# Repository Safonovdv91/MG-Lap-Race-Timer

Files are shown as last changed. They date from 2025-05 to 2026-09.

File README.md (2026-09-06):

# Проект MG-Lap-Race-Timer
Фотобарьер работающий на базе esp32-s3(или аналоги). Проектирование вед я создал проект, опиши мне подробную инструкцию по реализации схемы,
**MG-Lap-Race-Timer** — это система хронометража для спортивных мероприятий, использующая инфракрасные (ИК - TSAL6200, или аналог, Лазерный 940 нм) излучатель и фотодиод(BPW34, vishay ) для отслеживания времени круга и скорости. Система состоит из двух основных компонентов: **передатчика** и **приемника**, оба на базе микроконтроллера ESP32.

## Основные возможности

- **Измерение времени круга:** Точное отслеживание времени прохождения круга.
- **Измерение скорости:** Расчет скорости на основе времени пересечения луча.
- **Веб-интерфейс:** Удобный интерфейс для просмотра результатов в реальном времени, доступный с любого устройства с Wi-Fi.
- **Беспроводная телеметрия:** Передатчик отправляет данные о состоянии своей батареи на приемник.
- **Гибкая настройка:** Возможность изменения режимов работы и других параметров через веб-интерфейс.

## Архитектура

Система разделена на два устройства:

### 1. Передатчик (Transmitter)

- **Задача:** Генерировать постоянный ИК-сигнал или Laser-сигнал.
- **Функционал:**
  - ИК (LASER)-сигнал.
  - Измерение напряжения аккумулятора
  - Передача телеметрии(напряжение, вкл \выкл луч) по ESP-NOW на Receiver
  - Отображение заряда через LED
  - Hearbeat работы

 - **Принцип работы**
 - Шим сигнал ESP32 на GPIO13 D13 (частота 38кГц) через транзиcтор IRLZ44N.
  При duty = 50% использую х2 мощность(200мА) - TSAL6200

### 2. Приемник (Receiver)

- **Задача:** Обнаруживать пересечение ИК-луча и предоставлять интерфейс для пользователя.
- **Функционал:**
  - Создает точку доступа Wi-Fi.
  - Запускает веб-сервер, доступный по адресу `http://192.168.4.1`.
  - Регистрирует пересечение ИК(лазерного)-луча.
  - Рассчитывает время круга.
  - Отображает историю измерений.
  - Принимает и отображает данные телеметрии от передатчика.
  - Трансляция ESP-NOW с данными времени.

## Веб-интерфейс

Приемник предоставляет веб-интерфейс со следующими возможностями:

- **Выбор режима:**
  - **Секундомер круга (Lap Timer):** Измеряет время между двумя последовательными пересечениями одного датчика.
  - **Гоночный таймер (Race Timer):** Работает как стандартный секундомер, запускаемый первым датчиком и останавливаемый вторым.
- **Отображение данных:** Показывает текущее измерение, историю последних 5 измерений, а также состояние батарей приемника и передатчика.
- **Настройки:** Позволяет изменять расстояние между датчиками ( для режима спидометра) и настраивать параметры Wi-Fi.

## Аппаратное обеспечение

- **Микроконтроллер:** ESP32 DevKit V1 (или аналогичный).
- **Передатчик:** 
  - ИК-светодиоды(940нМ), laser излучатель.
  - Mosfet AO3400A, IRFL44N
  - TSAL6200. R1 = 100 Ом (Или из расчета пот току(обычно меньше 40мА)) В KY-008 не требуется.
- **Приемник:**
  - Светодиод BPW34 | Laser Detector | Vishay BPV10NF
  - Операционный усилитель - **LM358** / TLV2371 / OPA380.
  - Компаратор - **LM393** / LMV358
- **Обвязка:**
  - R:
    - 220 Ом
    - 2х 100 кОм
    - 1 МОм
  - C:
    - 0.1 мкФ 16В
    - 100 пФ
- **Источник питания:** 
  - Li-ion или Li-po аккумулятор. с повышающим модулем до 5В.
  - power boost li-ion -> 5В
  - Преобразователь 5В -> 3.3 В
  
### Схема подключения (пины)

#### Передатчик:

- `GPIO13 (D13)`: ИК-передатчик 1
- `GPIO34`: Датчик напряжения батареи(через делитель напряжения)

#### Приемник:

- `GPIO14`: ИК-приемник 1
- `GPIO34`: Датчик напряжения батареи(через делитель напряжения)

```
     (+) Батареи LiPo
           |
           |
         [ R1 ]  (1 МОм)
           |
           |---------------------> к пину GPIO 34 на ESP32
           |
         [ R2 ]  (300 кОм)
           |
           |---------------------> к пину GND (земля) на ESP32
           |
         [ C1 ]  (0.1 µF (100 nF) X7R 16 V или 25 V, керамика)
           |
            +---------------------> к пину GND (земля) на ESP32 (вторая нога конденсатора)
```

- `GPIO32 (D32)`: Светодиод статуса ( пересечения луча)
- `GPIO33 (D33)`: Светодиод режима измерений (запущен \ остановлен таймер)

## Сборка и прошивка

Проект использует [PlatformIO](https://platformio.org/).

1. **Установите PlatformIO Core** или [PlatformIO IDE for VSCode](https://platformio.org/install/ide?install=vscode).
2. Откройте проект в VSCode.
3. Для сборки и прошивки **передатчика** используйте команду:
   ```bash
   pio run -e transmitter -t upload
   ```
4. Для сборки и прошивки **приемника** используйте команду:
   ```bash
   pio run -e receiver -t upload
   ```

## Дальнейшее развитие

Проект имеет потенциал для улучшений:
- Добавление поддержки нескольких передатчиков.
- Сохранение истории измерений в энергонезависимой памяти.
- Улучшение безопасности веб-интерфейса.
- Оптимизация энергопотребления.

Элементная база:
esp32 devkit 30pin - основной модуль обработки логики, используется 
Точечный ИК-фотодиод Vishay BPV10NF для отслеживания пересечения луча
LM358P - усилитель сигнала луча
LM393N - компаратор для получения логического уровня и передача логического сигнала после сравнения с заданным сигналом и сигналом после LM358P
MT3608 - модуль заряда и питания, с выводом 5В. Запитан от LiIon21700 4500mAh
LM117T - если необходим можно использовать
Светодиоды для отображения логики(информация для отображения)

Подключение к ESP32:
GPIO13 - Выход LM393N
GPIO32 - светодиод 1
GPIO33 - светодиод 2

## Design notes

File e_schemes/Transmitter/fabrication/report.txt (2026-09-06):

Предупреждение: Коррекция ширины ограничена.  Значение коррекции ширины должно быть в пределах [0,000001 mm; 0,199999 mm] для текущих правил проектирования.
Начерчено в '/home/dsafonov/Embeded/MG-Lap-Race-Timer/e_schemes/Transmitter/Transmitter-F_Cu.gbr'.
Начерчено в '/home/dsafonov/Embeded/MG-Lap-Race-Timer/e_schemes/Transmitter/Transmitter-B_Cu.gbr'.
Начерчено в '/home/dsafonov/Embeded/MG-Lap-Race-Timer/e_schemes/Transmitter/Transmitter-F_Paste.gbr'.
Начерчено в '/home/dsafonov/Embeded/MG-Lap-Race-Timer/e_schemes/Transmitter/Transmitter-B_Paste.gbr'.
Начерчено в '/home/dsafonov/Embeded/MG-Lap-Race-Timer/e_schemes/Transmitter/Transmitter-F_Silkscreen.gbr'.
Начерчено в '/home/dsafonov/Embeded/MG-Lap-Race-Timer/e_schemes/Transmitter/Transmitter-B_Silkscreen.gbr'.
Начерчено в '/home/dsafonov/Embeded/MG-Lap-Race-Timer/e_schemes/Transmitter/Transmitter-F_Mask.gbr'.
Начерчено в '/home/dsafonov/Embeded/MG-Lap-Race-Timer/e_schemes/Transmitter/Transmitter-B_Mask.gbr'.
Начерчено в '/home/dsafonov/Embeded/MG-Lap-Race-Timer/e_schemes/Transmitter/Transmitter-Edge_Cuts.gbr'.
Создан файл Gerber Job '/home/dsafonov/Embeded/MG-Lap-Race-Timer/e_schemes/Transmitter/Transmitter-job.gbrjob'.
Информация: Готово.
Информация: Готово.

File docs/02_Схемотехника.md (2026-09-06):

# Питание
```
Li-Ion 3.7-4.2В
      |
      v
[TP4056 (зарядка)]
      |
      | 3.7-4.2В
      v
[MT3608 (Step-up)] -- 5В --+-- [Понижающий модуль на 3.3В] -- 3.3В -- ESP32
                           |
                           +-- USB Type-C (для питания исполнительных модулей 5В)
```

# Шпаргалка по монтажу кнопок

## Компоненты для излучателя

## Компоненты (на каждую кнопку):
GPIO ESP32 - 3.3 В 13 mA
ESP32-WROOM-32UE (пины GPIO 18 и GPIO 19).
Резистор R1: 10 кОм (номинал: коричневый-черный-оранжевый).
Конденсатор C1: 100 нФ (0.1 мкФ). Обозначение на корпусе "104".
Кнопка: Тактовая кнопка (замыкающая).

### Инструкция по монтажу:
#### Питание (самое важное):
        Подключите 3.3В от вашего стабилизатора к выводу питания модуля (обычно это крайний пин с одной стороны, обозначенный как 3V3).
        Подключите GND от стабилизатора к пину GND модуля.
        Это общая шина питания, от которой мы будем питать и кнопки.
#### Резистор (Pull-up):
        Возьмите резистор 10 кОм.
        Одним концом подключите его к линии питания 3.3В.
        Другим концом подключите его к пину GPIO 18 модуля.
#### Конденсатор (Фильтр):
        Возьмите конденсатор 100 нФ.
        Одну ножку конденсатора подключите к тому же пину GPIO 18 (в ту же точку, куда приходит резистор).
        Вторую ножку конденсатора подключите к общей линии GND.
        Конденсатор должен быть расположен как можно ближе к ножке GPIO физически, чтобы он эффективно ловил помехи.

#### Кнопка:

Один контакт кнопки подключите к тому же GPIO 18.
Второй контакт кнопки подключите к GND.
Когда кнопка не нажата, резистор держит на GPIO высокий уровень (3.3В). Когда кнопка нажата, она замыкает GPIO на землю (GND), преодолевая сопротивление резистора.

```C
void setup() {
  Serial.begin(115200);
  // Режим входа (без подтяжки! мы использовали внешний резистор 10k)
  pinMode(BTN1, INPUT);
  pinMode(BTN2, INPUT);
  Serial.println("ESP32-WROOM-32UE готов к работе");
}
```

# Приемник

 Схема работает на принципе получени сигнала через фотодиод или ИК-фотодиод. Для улучшения

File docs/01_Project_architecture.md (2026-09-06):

# Архитектурный план проекта кругового таймера

## Текущее состояние

- В проекте излучатель и приемник ИК сигнала находятся на разных ESP32
- ИК или лазер передатчики работают на пинах GPIO 13(возможна запитка напрямую от питания 5В), но желательно через
МОСФЕТ транзистор иметь возможность управлять
- ИК приемники подключены к пинам GPIO 14
- Уровень заряда определяем через делитель напряжения GPIO 34

## Цель

Проект разделен на две независимые прошивки:

1. Излучатель (transmitter):
 - передача ИК сигнала или сигнала лазера
 - передача данных о заряде батареи(телеметрия излучателя)

2. Приемник (receiver):

  - прием ИК сигнала
  - веб-сервер для отображения данных
  - ведение секундомера пересечения
  - FEATURE: передача данных через ESP-NOW

## Коммуникация

- Используется Wi-Fi с UDP для связи между телефоном\ноутбуком
- Для связи с другими ESP использцется внутренний протокол ESP-NOW
- Приемник будет получать информацию о состоянии излучателя (например, уровень заряда батареи)

## Назначение пинов 
### (DI) Управленее\прием сигнала диодом  
- GPIO 13 - Приемник ( определение пересечения луча) / излучатель

Подтяжка к GND
- GPIO 18 Кнопка 1 
- GPIO 19 Кнопка 2

  // Режим входа (без подтяжки! мы использовали внешний резистор 10k)
  pinMode(BTN1, INPUT);
  pinMode(BTN2, INPUT);

### (DO) Светодиоды 220 Ом - GND 
- GPIO 32 - Определение статуса излучателя( Горит - луч пойман)
- GPIO 33 - Пин мода  операции выполнения
- GPIO 25 - Резервный светодиод

Резерв: 26

### (AI) Определенеи  
- GPIO 34 - Определение заряда батареи

### (AO)

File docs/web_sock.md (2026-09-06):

# Архитектура реального времени с WebSockets

Этот документ описывает архитектуру обмена данными между таймером (ESP32) и клиентскими устройствами (веб-браузер, другие ESP32) с использованием технологии WebSocket. Эта архитектура была внедрена для замены устаревшей и медленной модели опроса по HTTP (HTTP Polling).

## 1. Обзор архитектуры

Основная идея — переход от модели "клиент спрашивает" (pull) к модели "сервер сообщает" (push).

*   **Сервер (ESP32-приемник):** Работает как WebSocket-сервер. Он больше не ждет периодических запросов от клиентов. Вместо этого, он **мгновенно рассылает (push) пакеты данных** всем подключенным клиентам в тот момент, когда в системе происходит значимое событие (старт таймера, финиш, смена режима).

*   **Клиент (Браузер или другая ESP32):** Выступает в роли WebSocket-клиента. При запуске он устанавливает **одно постоянное соединение** с сервером и затем пассивно "слушает" входящие сообщения. Это гораздо эффективнее, чем постоянно отправлять запросы.

*   **Формат данных (JSON):** Обмен данными происходит с помощью стандартизированных JSON-сообщений, которые содержат полное состояние таймера в текущий момент времени.

## 2. Изменения в коде

### Конфигурация (`platformio.ini`)

1.  **Добавлена библиотека:** В `lib_deps` для окружения `Receiver-RX` была добавлена зависимость `links2004/WebSockets@^2.4.1`.
2.  **Обновлен фильтр сборки:** В `src_filter` был добавлен файл `+<websocket_handlers.cpp>`, чтобы компилятор включил его в прошивку.

### Бэкенд (Прошивка ESP32)

#### Новые файлы: `websocket_handlers.cpp` и `websocket_handlers.h`

Чтобы не загромождать основной код, вся логика работы с WebSocket вынесена в эти файлы.

*   `ws_init()`: Инициализирует WebSocket-сервер на порту 81.
*   `ws_loop()`: Эту функцию необходимо постоянно вызывать в главном цикле `loop()` для обработки событий WebSocket (подключения, отключения, прием данных).
*   `onWebSocketEvent()`: Внутренняя функция-обработчик. Она вызывается, когда клиент подключается или отключается. При новом подключении она немедленно отправляет ему текущее состояние таймера.
*   `ws_broadcast_data()`: **Ключевая функция.** Она собирает все актуальные данные (режим, время, статус, история, заряд батарей) в один JSON-объект и рассылает его всем подключенным клиентам.

#### Интеграция (`receiver_main.cpp`)

*   В `setup()` теперь вызывается `ws_init()` для запуска WebSocket-сервера.
*   В `loop()` теперь постоянно вызывается `ws_loop()`.
*   URL `/api/v1/data` и его обработчик `handleData()` были полностью удалены за ненадобностью.

#### Отправка данных (`measurements.cpp`)

Это "сердце" новой системы. Функция `ws_broadcast_data()` теперь вызывается в следующие моменты:

1.  **При смене состояния:** Сразу после того, как таймер переходит в новое состояние (`READY`, `RUNNING`, `DISPLAY`). Это обеспечивает мгновенную реакцию интерфейса.
2.  **Во время замера:** Пока таймер находится в состоянии `RUNNING`, данные отправляются каждые **100 мс**. Это создает эффект "живого" обновления времени на экране без слишком большой нагрузки на сеть.
3.  **При подключении нового клиента:** Чтобы новый пользователь сразу увидел актуальное состояние.

### Фронтенд (`script.js`)

Клиентский скрипт был полностью переписан.

*   **Отказ от `fetch`:** Весь механизм `setInterval` и `fetch`, который раньше опрашивал сервер каждые 300 мс, удален.
*   **Установка соединения:** При загрузке страницы скрипт пытается установить WebSocket-соединение с сервером по адресу `ws://{hostname}:81/`.
*   **Обработка событий:**
    *   `onopen`: Соединение успешно установлено.
    *   `onclose`: Соединение потеряно. Скрипт автоматически пытается переподключиться каждые 2 секунды.
    *   `onmessage`: **Самая главная часть.** Эта функция вызывается каждый раз, когда от сервера приходит JSON-сообщение. Она парсит эти данные и обновляет ВЕСЬ интерфейс: цифровой дисплей, цветной индикатор статуса, историю кругов, индикаторы батарей.

## 3. Преимущества нового подхода

1.  **Низкая задержка:** Реакция интерфейса на события практически мгновенная.
2.  **Высокая эффективность:** Нагрузка на процессор ESP32, сеть Wi-Fi и устройство клиента значительно снижена, так как данные передаются только по делу.
3.  **Масштабируемость:** Архитектура позволяет легко подключать несколько клиентов (несколько браузеров, другие ESP32), и все они будут получать данные одновременно и эффективно.

## 4. Как подключить вторую ESP32 с экраном

Благодаря новой архитектуре, это стало просто:

1.  На второй ESP32 нужно использовать ту же библиотеку `WebSockets` в режиме **клиента**.
2.  В коде нужно будет подключиться к Wi-Fi сети основного таймера.
3.  После этого установить WebSocket-соединение с IP-адресом основного таймера и портом 81.
4.  В цикле слушать входящие сообщения (`onmessage`), парсить JSON и выводить нужные данные (`value`, `timer_status` и т.д.) на подключенный дисплей.

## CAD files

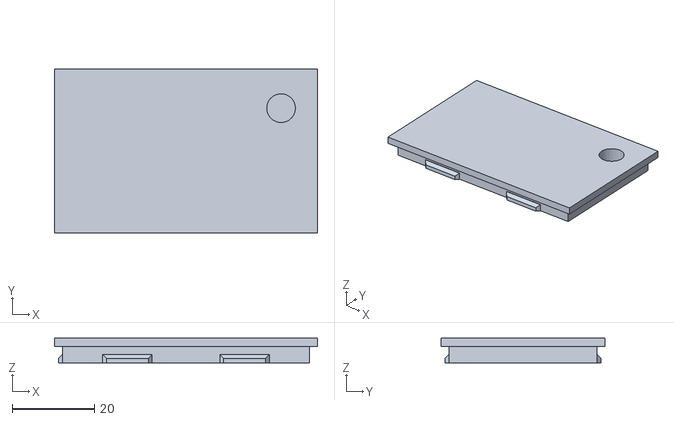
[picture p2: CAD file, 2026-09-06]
3d model /ESP32 Case-Крышка.stl
64.0 x 40.0 x 6.00

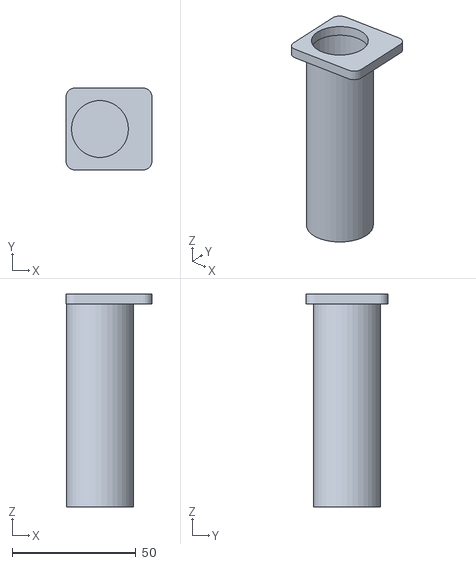
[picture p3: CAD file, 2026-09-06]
3d model /ESP32 Case- Батарейка.stl
34.7 x 33.1 x 86.0

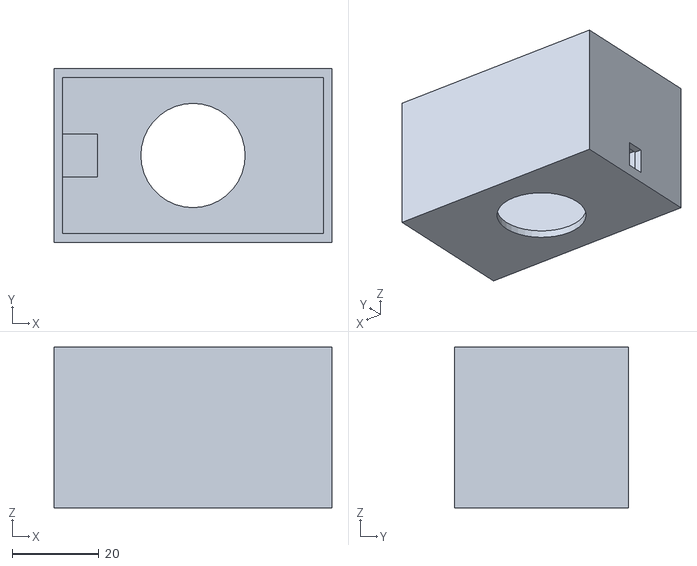
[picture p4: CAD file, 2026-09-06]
3d model /ESP32 Case-ESP32 Case.stl
64.0 x 40.0 x 37.0

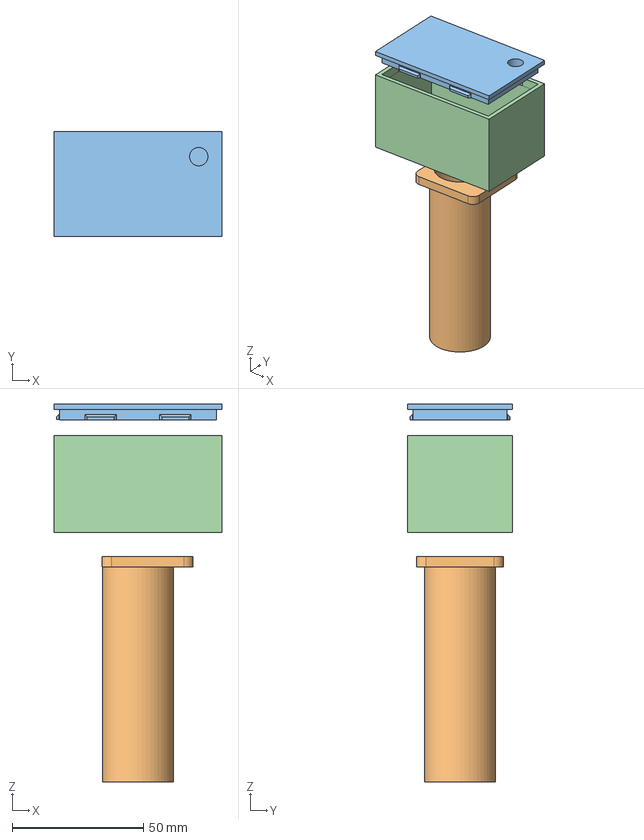
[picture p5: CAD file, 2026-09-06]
3d model /ESP32 Case.FCStd
64.0 x 40.0 x 144.0 mm
ESP32 Case
Battery Case
Крышка001

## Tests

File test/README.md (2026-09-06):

# 🧪 Тестирование MG-Lap-Race-Timer

## 📖 Оглавление

1. [Быстрый старт](#быстрый-старт)
2. [Структура тестов](#структура-тестов)
3. [Команды запуска](#команды-запуска)
4. [Написание новых тестов](#написание-новых-тестов)
5. [Моки и заглушки](#моки-и-заглушки)

---

## 🚀 Быстрый старт

### 1. Установка зависимостей

```bash
# Установите PlatformIO CLI (если не установлен)
pip install platformio

# Или через Homebrew (macOS)
brew install platformio
```

### 2. Запуск всех тестов

```bash
pio test
```

### 3. Запуск конкретного теста

```bash
# Тесты батареи
pio test -f test_battery

# Тесты ядра измерений
pio test -f test_measurement_core
```

### 4. Запуск с подробным выводом

```bash
pio test -v
```

---

## 📁 Структура тестов

```
test/
├── battery/
│   └── test_battery.cpp           # Тесты модуля battery.cpp
├── core/
│   └── test_measurement_core.cpp  # Тесты measurement_core.cpp
├── mocks/
│   └── arduino_mocks.h            # Заглушки Arduino API (TODO)
└── README.md                      # Этот файл
```

---

## 🎯 Команды запуска

| Команда | Описание |
|---|---|
| `pio test` | Запуск всех тестов |
| `pio test -f test_battery` | Запуск тестов батареи |
| `pio test -f test_measurement_core` | Запуск тестов ядра измерений |
| `pio test -v` | Подробный вывод (verbose) |
| `pio test --without-building` | Запуск без пересборки |
| `pio test --without-testing` | Только сборка, без запуска |

---

## ✍️ Написание новых тестов

### Шаблон теста

Создайте файл `test/<module>/test_<name>.cpp`:

```cpp
#include <unity.h>
#include <Arduino.h>

// Подключаем тестируемый модуль
#include "path/to/module.h"

// Тестовая функция
void test_example(void) {
    int result = someFunction(5);
    TEST_ASSERT_EQUAL_INT(10, result);
}

// Настройка (перед каждым тестом)
void setUp(void) {
    // Инициализация
}

// Очистка (после каждого теста)
void tearDown(void) {
    // Очистка
}

// Главная функция
int runUnityTests(void) {
    UNITY_BEGIN();
    RUN_TEST(test_example);
    return UNITY_END();
}

void setup() {
    runUnityTests();
}

void loop() {}

int main(int argc, char **argv) {
    return runUnityTests();
}
```

### Основные макросы Unity

| Макрос | Описание |
|---|---|
| `TEST_ASSERT_EQUAL_INT(expected, actual)` | Проверка целых чисел |
| `TEST_ASSERT_EQUAL_FLOAT(expected, actual)` | Проверка float |
| `TEST_ASSERT_TRUE(condition)` | Проверка истинности |
| `TEST_ASSERT_NULL(pointer)` | Проверка на NULL |
| `TEST_ASSERT_NOT_NULL(pointer)` | Проверка на не-NULL |
| `TEST_ASSERT_GREATER_OR_EQUAL_INT(min, actual)` | Проверка >= |
| `TEST_ASSERT_LESS_OR_EQUAL_INT(max, actual)` | Проверка <= |

---

## 🔧 Моки и заглушки

### Проблема

Код использует Arduino/ESP32 API (`Serial`, `micros`, `millis`, `portENTER_CRITICAL`), 
которые недоступны в нативных тестах.

### Решение (TODO)

Создайте `test/mocks/arduino_mocks.h`:

```cpp
#ifndef ARDUINO_MOCKS_H
#define ARDUINO_MOCKS_H

#include <stdint.h>
#include <stdio.h>

// Мок для Serial
struct SerialMock {
    void printf(const char* fmt, ...) {
        // Пустая реализация для тестов
    }
};
extern SerialMock Serial;

// Мок для millis/micros
extern unsigned long mock_millis_time;
extern unsigned long mock_micros_time;

unsigned long millis() { return mock_millis_time; }
unsigned long micros() { return mock_micros_time; }

// Мок для критических секций
#define portENTER_CRITICAL(x)
#define portEXIT_CRITICAL(x)
#define portENTER_CRITICAL_ISR(x)
#define portEXIT_CRITICAL_ISR(x)

// Мок для IRAM_ATTR
#define IRAM_ATTR

#endif
```

---

## 📊 Покрытие кода

### Текущий статус

| Модуль | Статус | Файл теста |
|---|---|---|
| `battery.cpp` | ✅ Готово | `test/battery/test_battery.cpp` |
| `measurement_core.cpp` | ✅ Готово | `test/core/test_measurement_core.cpp` |
| `config.cpp` | ⏳ Ожидает | - |
| `espnow_*.cpp` | ⏳ Ожидает | - |
| `web_*.cpp` | ⏳ Ожидает | - |

### План покрытия

1. **Приоритет 1** (чистая логика, без зависимостей):
   - ✅ `battery.cpp` → `calculateBatteryPercentage()`
   - ✅ `measurement_core.cpp` → `addToHistory()`, `handleCooldown()`, `updateLiveTimer()`

2. **Приоритет 2** (требуют моков):
   - `config.cpp` → загрузка/сохранение настроек
   - `transmitter_data.cpp` → обработка данных

3. **Приоритет 3** (интеграционные тесты):
   - `espnow_*.cpp` → требуют моков ESP-NOW
   - `web_*.cpp` → требуют моков WebSocket

---

## 🐛 Отладка тестов

### Ошибки компиляции

```bash
# Ошибка: Arduino.h не найден
# Решение: PlatformIO автоматически подключает фреймворк
# Проверьте platformio.ini

# Ошибка: undefined reference
# Решение: Добавьте исходный файл в test_src_filter
```

### Ошибки выполнения

```bash
# Segmentation fault
# Причина: доступ к памяти ESP32 в нативном тесте
# Решение: Используйте моки для hardware-specific кода
```

---

## 📚 Ресурсы

- [PlatformIO Unit Testing](https://docs.platformio.org/en/latest/advanced/unit-testing/index.html)
- [Unity Test Framework](https://github.com/ThrowTheSwitch/Unity)
- [CppUTest](https://cpputest.github.io/) - альтернатива для C++

---

## ❓ FAQ

**Q: Тесты не запускаются на ESP32?**  
A: PlatformIO Test может запускать тесты как на хосте (native), так и на устройстве. 
   Для unit-тестов используйте native-режим (по умолчанию).

**Q: Как тестировать код с Serial?**  
A: Создайте мок для Serial (см. раздел [Моки и заглушки](#моки-и-заглушки)).

**Q: Можно ли запускать тесты в CI/CD?**  
A: Да! Добавьте шаг `pio test` в ваш pipeline (GitHub Actions, GitLab CI, etc.).

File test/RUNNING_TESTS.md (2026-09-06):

# 🧪 Тестирование MG-Lap-Race-Timer

## 📖 Оглавление

1. [Быстрый старт](#быстрый-старт)
2. [Структура проекта](#структура-проекта)
3. [Структура тестов](#структура-тестов)
4. [Команды запуска](#команды-запуска)
5. [Написание новых тестов](#написание-новых-тестов)
6. [Моки и заглушки](#моки-и-заглушки)

---

## 🚀 Быстрый старт

### 1. Установка зависимостей

```bash
# Установите PlatformIO CLI (если не установлен)
pip install platformio

# Или через Homebrew (macOS)
brew install platformio
```

### 2. Запуск всех тестов

```bash
pio test -e native-tests
```

### 3. Запуск с подробным выводом

```bash
pio test -e native-tests -v
```

**Ожидаемый результат:**
```
test/test_all.cpp:187:test_battery_100_percent:PASS
test/test_all.cpp:188:test_battery_90_percent:PASS
...
-----------------------
16 Tests 0 Failures 0 Ignored 
OK
```

---

## 📁 Структура проекта

```
project/
├── include/              # Публичные заголовки
│   ├── core/             # Ядро системы
│   ├── drivers/          # Драйверы периферии
│   ├── modules/          # Бизнес-логика модулей
│   └── utils/            # Утилиты (конфиги)
├── src/                  # Исходный код
│   ├── core/             # Ядро системы (main файлы)
│   ├── drivers/          # Драйверы периферии
│   ├── modules/          # Бизнес-логика модулей
│   └── utils/            # Утилиты
├── test/                 # Тесты
│   ├── test_all.cpp      # Все unit-тесты
│   └── fixtures/
│       └── mocks/        # Заглушки и моки
├── scripts/              # Скрипты деплоя и CI
├── platformio.ini        # Конфигурация сборки
└── README.md             # Документация
```

### Детализация по директориям

| Директория | Описание | Примеры |
|---|---|---|
| `src/core/` | Ядро системы, main файлы | `receiver_main.cpp`, `tx_main.cpp` |
| `src/drivers/` | Драйверы периферии | `battery/`, `espnow_*.cpp`, `ir_transmitter.cpp` |
| `src/modules/` | Бизнес-логика | `web_handlers.cpp`, `transmitter_data.cpp` |
| `src/utils/` | Утилиты | `config.cpp` |
| `include/core/` | Заголовки ядра | `measurement_core.h` |
| `include/drivers/` | Заголовки драйверов | `espnow_receiver.h`, `battery/` |
| `include/modules/` | Заголовки модулей | `web_handlers.h`, `measurements.h` |
| `include/utils/` | Заголовки утилит | `config.h`, `receiver_config.h` |
| `test/fixtures/mocks/` | Моки для тестов | `arduino_mocks.cpp`, `arduino_mocks.h` |

---

## 📁 Структура тестов

```
test/
├── test_all.cpp              # Все тесты (16 тестов)
├── fixtures/
│   └── mocks/
│       ├── arduino_mocks.h   # Заголовки моков
│       └── arduino_mocks.cpp # Реализация моков
├── RUNNING_TESTS.md          # Этот файл
├── TESTING_PLAN.md           # План тестирования
├── QUICKSTART.md             # Быстрый старт
└── README.md                 # Общая документация
```

### Тестируемые модули

| Модуль | Файл | Кол-во тестов |
|---|---|---|
| `battery.cpp` | `src/drivers/battery/battery.cpp` | 9 тестов |
| `measurement_core.cpp` | `src/core/measurement_core.cpp` | 7 тестов |

---

## 🎯 Команды запуска

| Команда | Описание |
|---|---|
| `pio test -e native-tests` | Запуск всех тестов |
| `pio test -e native-tests -v` | Подробный вывод (verbose) |
| `pio test -e native-tests --without-building` | Запуск без пересборки |
| `pio test -e native-tests --without-testing` | Только сборка, без запуска |

### ❌ Не работает (устарело)

```bash
# Эти команды НЕ работают - используйте native-tests
pio test -e native          # НЕ РАБОТАЕТ
pio test -e native -f test_battery  # НЕ РАБОТАЕТ
```

---

## ✍️ Написание новых тестов

### Шаг 1: Добавить тест в test/test_all.cpp

Открой `test/test_all.cpp` и добавь новую тестовую функцию:

```cpp
void test_my_function(void) {
    int result = myFunction(5);
    TEST_ASSERT_EQUAL_INT(10, result);
}
```

### Шаг 2: Добавить тест в runUnityTests()

```cpp
int runUnityTests(void) {
    UNITY_BEGIN();
    
    // ... существующие тесты
    
    // Новый тест
    RUN_TEST(test_my_function);
    
    return UNITY_END();
}
```

### Шаг 3: Запустить тест

```bash
pio test -e native-tests -v
```

### Основные макросы Unity

| Макрос | Описание |
|---|---|
| `TEST_ASSERT_EQUAL_INT(expected, actual)` | Проверка целых чисел |
| `TEST_ASSERT_EQUAL_FLOAT(expected, actual)` | Проверка float |
| `TEST_ASSERT_TRUE(condition)` | Проверка истинности |
| `TEST_ASSERT_NULL(pointer)` | Проверка на NULL |
| `TEST_ASSERT_NOT_NULL(pointer)` | Проверка на не-NULL |
| `TEST_ASSERT_GREATER_OR_EQUAL_INT(min, actual)` | Проверка >= |
| `TEST_ASSERT_LESS_OR_EQUAL_INT(max, actual)` | Проверка <= |

---

## 🔧 Моки и заглушки

Моки находятся в `test/fixtures/mocks/` и предоставляют заглушки для:

- `Serial` — вывод отладочной информации
- `millis()`, `micros()` — функции времени
- `analogRead()`, `analogSetPinAttenuation()` — АЦП
- `portENTER_CRITICAL()`, `portEXIT_CRITICAL()` — критические секции
- `Preferences` — хранение настроек
- `pinMode()`, `digitalWrite()`, `digitalRead()` — GPIO

### Как это работает

```cpp
// В исходных файлах (.cpp, .h)
#ifdef UNIT_TEST
    #include "fixtures/mocks/arduino_mocks.h"  // Моки для тестов
#else
    #include <Arduino.h>              // Реальный Arduino.h для ESP32
#endif
```

---

## 📊 Покрытие кода

### Текущий статус

| Модуль | Статус | Файл теста |
|---|---|---|
| `battery.cpp` | ✅ Готово | `test/test_all.cpp` |
| `measurement_core.cpp` | ✅ Готово | `test/test_all.cpp` |
| `config.cpp` | ⏳ Ожидает | - |
| `transmitter_data.cpp` | ⏳ Ожидает | - |
| `espnow_*.cpp` | ⏳ Ожидает | - |
| `web_*.cpp` | ⏳ Ожидает | - |

**Пройдено тестов:** 16 ✅

### План покрытия

1. **Приоритет 1** (чистая логика, без зависимостей):
   - ✅ `battery.cpp` → `calculateBatteryPercentage()`
   - ✅ `measurement_core.cpp` → `addToHistory()`, `handleCooldown()`, `updateLiveTimer()`

2. **Приоритет 2** (требуют моков):
   - ⏳ `config.cpp` → загрузка/сохранение настроек
   - ⏳ `transmitter_data.cpp` → обработка данных

3. **Приоритет 3** (интеграционные тесты):
   - ⏳ `espnow_*.cpp` → требуют моков ESP-NOW
   - ⏳ `web_*.cpp` → требуют моков WebSocket

---

## 🐛 Отладка тестов

### Ошибки компиляции

```bash
# Ошибка: Arduino.h не найден
# Решение: Убедитесь что определён UNIT_TEST в platformio.ini

# Ошибка: undefined reference
# Решение: Проверьте что моки подключены в test_all.cpp
```

### Ошибки выполнения

```bash
# Segmentation fault
# Причина: доступ к памяти ESP32 в нативном тесте
# Решение: Используйте моки для hardware-specific кода
```

### Тесты не запускаются

**Решение:**

```bash
# Очистите кэш и пересоберите
rm -rf .pio
pio test -e native-tests -v
```

---

## 📚 Ресурсы

- [PlatformIO Unit Testing](https://docs.platformio.org/en/latest/advanced/unit-testing/index.html)
- [Unity Test Framework](https://github.com/ThrowTheSwitch/Unity)
- [test/TESTING_PLAN.md](TESTING_PLAN.md) — План тестирования
- [test/QUICKSTART.md](QUICKSTART.md) — Быстрый старт

---

## ❓ FAQ

**Q: Почему все тесты в одном файле?**  
A: Для упрощения сборки в PlatformIO. Все тесты компилируются вместе с моками.

**Q: Как тестировать код с Serial?**  
A: Моки предоставляют `SerialMock` который игнорирует вывод (или выводит в stdout при `DEBUG_TESTS`).

**Q: Можно ли запускать тесты в CI/CD?**  
A: Да! Добавьте шаг `pio test -e native-tests` в ваш pipeline (GitHub Actions, GitLab CI, etc.).

**Q: Как добавить новый тест?**  
A: См. раздел [Написание новых тестов](#написание-новых-тестов).

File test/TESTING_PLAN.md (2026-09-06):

# 📋 План покрытия кода тестами

## 🎯 Цель

Покрыть тестами критическую бизнес-логику проекта MG-Lap-Race-Timer для обеспечения надёжности и возможности рефакторинга.

---

## 📊 Текущий статус

| Модуль | Файл | Статус | Тесты |
|---|---|---|---|
| `battery.cpp` | `src/drivers/battery/battery.cpp` | ✅ Готово | `test/test_all.cpp` |
| `measurement_core.cpp` | `src/core/measurement_core.cpp` | ✅ Готово | `test/test_all.cpp` |
| `config.cpp` | `src/utils/config.cpp` | ⏳ Ожидает | - |
| `transmitter_data.cpp` | `src/modules/transmitter_data.cpp` | ⏳ Ожидает | - |
| `espnow_*.cpp` | `src/drivers/espnow_*.cpp` | ⏳ Ожидает | - |
| `web_*.cpp` | `src/modules/web_*.cpp` | ⏳ Ожидает | - |

**Пройдено тестов:** 16 ✅

---

## 🚀 Быстрый старт

```bash
# Запуск всех тестов
pio test -e native-tests

# Подробный вывод
pio test -e native-tests -v
```

---

## 🗺️ Дорожная карта тестирования

### Этап 1: Базовые модули (выполнено)

**Цель:** Покрыть тестами модули без внешних зависимостей

- ✅ `battery.cpp` — функция `calculateBatteryPercentage()` (9 тестов)
- ✅ `measurement_core.cpp` — функции:
  - `addToHistory()` (2 теста)
  - `handleCooldown()` (2 теста)
  - `updateLiveTimer()` (3 теста)

**Файл:**
- `test/test_all.cpp` — все тесты (16 тестов)

**Результат:** 16 тестов ✅

---

### Этап 2: Модули средней сложности

**Цель:** Покрыть тестами модули с минимальными зависимостями

#### 2.1 `config.cpp`

**Функции для тестирования:**
- `loadWiFiSettings()` — загрузка настроек WiFi
- `saveWiFiSettings()` — сохранение настроек

**Требуется:**
- Моки для `Preferences` (хранение настроек)
- Моки для `Serial`

**Приоритет:** Средний

#### 2.2 `transmitter_data.cpp`

**Функции для тестирования:**
- Обработка данных перед отправкой
- Форматирование пакетов

**Требуется:**
- Моки для структур данных

**Приоритет:** Средний

---

### Этап 3: Сложные модули

**Цель:** Покрыть тестами модули с внешними зависимостями

#### 3.1 `espnow_*.cpp`

**Файлы:**
- `src/drivers/espnow_transmitter.cpp`
- `src/drivers/espnow_receiver.cpp`
- `src/drivers/espnow_broadcast.cpp`

**Функции для тестирования:**
- Инициализация ESP-NOW
- Отправка/приём пакетов
- Обработка ошибок

**Требуется:**
- Моки для ESP-NOW API
- Моки для WiFi

**Приоритет:** Низкий (интеграционные тесты сложнее)

#### 3.2 `web_*.cpp`

**Файлы:**
- `src/modules/web_handlers.cpp`
- `src/modules/web_content.cpp`
- `src/modules/websocket_handlers.cpp`

**Функции для тестирования:**
- HTTP обработчики
- WebSocket сообщения
- Генерация HTML/JSON

**Требуется:**
- Моки для WebServer
- Моки для WebSocket
- Моки для ArduinoJson

**Приоритет:** Низкий

---

## 🏗️ Архитектура тестов

### Структура директорий

```
project/
├── test/
│   ├── test_all.cpp                 # Все тесты
│   └── fixtures/
│       └── mocks/                   # Моки Arduino/ESP32
├── src/
│   ├── core/                        # Ядро
│   ├── drivers/                     # Драйверы
│   ├── modules/                     # Модули
│   └── utils/                       # Утилиты
└── include/
    ├── core/
    ├── drivers/
    ├── modules/
    └── utils/
```

### Зависимости между компонентами

```
┌─────────────────────────────────────────────────────────┐
│                    Тестовый файл                        │
│                  (test/test_all.cpp)                    │
└────────────────────┬────────────────────────────────────┘
                     │
                     ▼
┌─────────────────────────────────────────────────────────┐
│              Arduino/ESP32 Mocks                        │
│         (test/fixtures/mocks/arduino_mocks.*)           │
│  - Serial, millis(), micros()                           │
│  - portENTER_CRITICAL, portEXIT_CRITICAL                │
│  - Preferences, analogRead                              │
└────────────────────┬────────────────────────────────────┘
                     │
                     ▼
┌─────────────────────────────────────────────────────────┐
│                  Исходный код                           │
│              (src/**/*.cpp)                             │
└─────────────────────────────────────────────────────────┘
```

---

## 🛠️ Инструменты

### PlatformIO Test Runner

**Установка:**
```bash
pip3 install platformio
```

**Команды:**
```bash
# Запуск всех тестов
pio test -e native-tests

# Запуск с подробным выводом
pio test -e native-tests -v

# Очистка и запуск
rm -rf .pio && pio test -e native-tests -v
```

### Unity Test Framework

Используется как фреймворк для unit-тестов.

**Основные макросы:**
- `TEST_ASSERT_EQUAL_INT(expected, actual)`
- `TEST_ASSERT_EQUAL_FLOAT(expected, actual)`
- `TEST_ASSERT_TRUE(condition)`
- `TEST_ASSERT_NULL(pointer)`

---

## 📝 Как писать новые тесты

### Шаг 1: Добавить тест в test/test_all.cpp

```cpp
void test_my_function(void) {
    int result = myFunction(5);
    TEST_ASSERT_EQUAL_INT(10, result);
}
```

### Шаг 2: Добавить в runUnityTests()

```cpp
int runUnityTests(void) {
    UNITY_BEGIN();
    
    // ... существующие тесты
    
    RUN_TEST(test_my_function);
    
    return UNITY_END();
}
```

### Шаг 3: Запустить

```bash
pio test -e native-tests -v
```

---

## 🎓 Советы для новичков в C

### 1. Начинайте с простых функций

Функции без побочных эффектов (без `Serial`, без `WiFi`) тестировать проще:

```cpp
// ✅ Легко: чистая функция
int calculateBatteryPercentage(float voltage) { ... }

// ❌ Сложно: функция с побочными эффектами
void sendViaESPNow(const char* data) { ... }
```

### 2. Используйте моки для внешних зависимостей

```cpp
// В исходных файлах
#ifdef UNIT_TEST
    #include "fixtures/mocks/arduino_mocks.h"
#else
    #include <Arduino.h>
#endif
```

### 3. Тестируйте одно поведение за раз

```cpp
// ✅ Хорошо: один тест — одна проверка
void test_battery_100_percent(void) { ... }
void test_battery_0_percent(void) { ... }

// ❌ Плохо: много проверок в одном тесте
void test_battery_all_cases(void) { ... }
```

### 4. Сбрасывайте состояние между тестами

```cpp
void setUp(void) {
    // Сброс глобальных переменных
    timerStatus = STATUS_READY;
    currentRaceTime = 0;
}
```

### 5. Используйте понятные имена тестов

```cpp
// ✅ Хорошо
void test_battery_100_percent(void)
void test_handleCooldown_ready_after_timeout(void)

// ❌ Плохо
void test1(void)
void test_battery(void)
```

---

## 🔍 Пример: Тестирование функции

### Исходная функция

```cpp
// src/drivers/battery/battery.cpp
int calculateBatteryPercentage(float voltage) {
    if (voltage >= 4.10) return 100;
    if (voltage >= 3.95) return 90 + (voltage - 3.95) * 100;
    // ...
    return 0;
}
```

### Тест

```cpp
// test/test_all.cpp
#include <unity.h>
#include "fixtures/mocks/arduino_mocks.cpp"
#include "src/drivers/battery/battery.cpp"

void test_battery_100_percent(void) {
    int result = calculateBatteryPercentage(4.20);
    TEST_ASSERT_EQUAL_INT(100, result);
}

void test_battery_0_percent(void) {
    int result = calculateBatteryPercentage(3.30);
    TEST_ASSERT_EQUAL_INT(0, result);
}

int runUnityTests(void) {
    UNITY_BEGIN();
    RUN_TEST(test_battery_100_percent);
    RUN_TEST(test_battery_0_percent);
    return UNITY_END();
}
```

### Запуск

```bash
pio test -e native-tests -v
```

---

## 📈 Метрики качества

### Целевые показатели

| Модуль | Целевое покрытие |
|---|---|
| `battery.cpp` | 90% |
| `measurement_core.cpp` | 80% |
| `config.cpp` | 70% |
| Остальные | 50%+ |

---

## 🚀 Следующие шаги

1. **Запустить существующие тесты**
   ```bash
   pio test -e native-tests
   ```

2. **Добавить тесты для `config.cpp`**
   - Протестировать загрузку/сохранение настроек

3. **Добавить тесты для `transmitter_data.cpp`**
   - Протестировать обработку данных

4. **Настроить CI/CD**
   - Добавить шаг `pio test -e native-tests` в GitHub Actions

---

## 📚 Ресурсы

- [PlatformIO Unit Testing](https://docs.platformio.org/en/latest/advanced/unit-testing/index.html)
- [Unity Test Framework](https://github.com/ThrowTheSwitch/Unity)
- [test/RUNNING_TESTS.md](RUNNING_TESTS.md) — Инструкция по запуску
- [test/QUICKSTART.md](QUICKSTART.md) — Быстрый старт

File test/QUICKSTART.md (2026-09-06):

# ⚡ Быстрый старт: Запуск тестов

## 1️⃣ Установка PlatformIO

```bash
# macOS
brew install platformio

# Или через pip
pip3 install platformio
```

## 2️⃣ Запуск тестов

```bash
# Перейдите в директорию проекта
cd /Users/safonov/Documents/MG-Lap-Race-Timer

# Запуск всех тестов
pio test -e native-tests

# Подробный вывод
pio test -e native-tests -v
```

## 3️⃣ Ожидаемый результат

```
test/test_all.cpp:187:test_battery_100_percent:PASS
test/test_all.cpp:188:test_battery_90_percent:PASS
test/test_all.cpp:189:test_battery_50_percent:PASS
...
-----------------------
16 Tests 0 Failures 0 Ignored 
OK
```

## 📚 Документация

- **test/TESTING_PLAN.md** — План покрытия кода тестами
- **test/README.md** — Общая документация по тестам

## 🆘 Помощь

Если тесты не запускаются, см. раздел "Решение проблем" в **test/TESTING_PLAN.md**

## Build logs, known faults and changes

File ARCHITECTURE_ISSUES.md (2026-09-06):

# Архитектурные проблемы проекта MG-Lap-Race-Timer

**Дата создания:** 20 февраля 2026  
**Статус:** Активный документ для отслеживания технического долга

---  Для продолжения этой сессии, выполните qwen --resume 4ae15635-b17d-4480-b5b9-cfc8339a5aa1

## 🔴 Критические (P0) — Требуют немедленного устранения

| # | Проблема | Файлы | Статус | Примечание |
|---|---|---|---|---|
| 0.1 | Глобальные `volatile` переменные без защиты от гонок | `measurements.cpp`, `measurements.h` | ✅ completed | Добавлены `getCurrentValueSafe()`, `getSensorActiveSafe()` |
| 0.2 | RACE CONDITION в `handleSensor()` ISR | `measurements.cpp` | ✅ completed | Добавлен `sensorTriggered` флаг, чтение в critical section |
| 0.3 | `resetMeasurements()` без critical section | `web_handlers.cpp` | ✅ completed | Обёрнуто в `lockMeasurements()/unlockMeasurements()` |
| 0.4 | Смешение логики и UI в `processMeasurements()` | `measurements.cpp` | ✅ completed | Выделено в `core/measurement_core.cpp` + `measurements_side_effects.cpp` |

---

## 🟠 Серьёзные (P1) — Устранить в ближайших итерациях

| # | Проблема | Файлы | Статус | Примечание |
|---|---|---|---|---|
| 1.1 | UDP вместо заявленного ESP-NOW | `receiver_main.cpp`, `transmitter_main.cpp` | ⬜ pending | В документации указан ESP-NOW, реализован UDP |
| 1.2 | Хардкод IP-адресов | `transmitter_main.cpp` | ✅ completed | Добавлен mDNS: `chrono.mg` |
| 1.3 | Нет обработки потерь Wi-Fi | `transmitter_main.cpp` | ⬜ pending | Отсутствует механизм реконнекта |
| 1.4 | `Serial.print()` в функциях получения данных | `battery.cpp` | ⬜ pending | Лишние аллокации, замедление работы |
| 1.5 | Статический `JsonDocument<1024>` может переполниться | `websocket_handlers.cpp` | ✅ completed | Увеличен до 1200, история ограничена 5 записями |
| 1.6 | SPIFFS: чтение HTML в `String` | `web_handlers.cpp` | ✅ completed | HTML отправляется через `streamFile()`, данные через WebSocket |

---

## 🟡 Дизайн-проблемы (P2) — Улучшения архитектуры

| # | Проблема | Файлы | Статус | Примечание |
|---|---|---|---|---|
| 2.1 | Дублирование конфигураций | `config.h`, `receiver_config.h`, `transmitter_config.h` | ⬜ pending | Пересекающиеся определения пинов, портов |
| 2.2 | Магические числа | `measurements.cpp`, `receiver_config.h` | ⬜ pending | `1.488`, `300000`, `4.0*1000` без имён |
| 2.3 | Нет модульности — большие файлы | `measurements.cpp` (300+ строк) | ⬜ pending | Разная ответственность в одном файле |
| 2.4 | C-стиль кода в C++ проекте | Все `.cpp` | ⬜ pending | Массивы вместо `std::array`, `sscanf`, ручное управление памятью |
| 2.5 | Глобальные переменные без инкапсуляции | `web_handlers.cpp`, `measurements.cpp` | ⬜ pending | `extern Mode currentMode`, `historyIndex` |

---

## 🟢 Потенциальные баги (P3) — Профилактика

| # | Проблема | Файлы | Статус | Примечание |
|---|---|---|---|---|
| 3.1 | Неиспользуемая переменная `beamBroken` | `measurements.cpp` | ⬜ pending | Объявлена, но логика работает через `beamBrokenNow` |
| 3.2 | Нет debounce для кнопок | `receiver_config.h` | ⬜ pending | GPIO 18, 19 зарезервированы, но нет обработки |
| 3.3 | Нет валидации входных данных | `web_handlers.cpp` | ⬜ pending | `handleUpdateWiFi()` — проверка длины, но не символов |
| 3.4 | Жёсткая привязка к пинам в коде | `receiver_config.h` | ⬜ pending | Сложно портировать на другую плату |

---

## 📋 Чеклист устранения

### Фаза 1: Критические исправления (P0)
- [x] **0.1** Добавить critical sections для всех операций с `volatile` переменными
- [x] **0.2** Рефакторинг `handleSensor()` — минимизировать логику в ISR
- [x] **0.3** Обернуть `resetMeasurements()` в critical section
- [x] **0.4** Выделить side effects (WebSocket, Serial) из `processMeasurements()`

### Фаза 2: Стабилизация связи (P1)
- [ ] **1.1** Интегрировать ESP-NOW вместо UDP
- [x] **1.2** Заменить хардкод IP на mDNS (`chrono.mg`)
- [ ] **1.3** Добавить автоматический реконнект Wi-Fi с экспоненциальной задержкой
- [ ] **1.4** Удалить `Serial.print()` из getter'ов, вынести в отдельную функцию логгирования
- [x] **1.5** Увеличить `JsonDocument` до 1200 байт (история ограничена 5 записями)
- [x] **1.6** Упростить код: HTML через `streamFile()`, данные через WebSocket (без замен на сервере)

### Фаза 3: Рефакторинг архитектуры (P2)
- [ ] **2.1** Создать единый `system_config.h` с наследованием для TX/RX
- [ ] **2.2** Заменить `#define` на `constexpr`, дать имена константам
- [ ] **2.3** Разделить `measurements.cpp` на модули:
  - `src/core/timer_fsm.cpp`
  - `src/core/sensor_reader.cpp`
  - `src/core/measurement_core.cpp`
- [ ] **2.4** Использовать `std::array`, `std::optional`, RAII
- [ ] **2.5** Инкапсулировать состояние в классы/структуры

### Фаза 4: Полировка (P3)
- [ ] **3.1** Удалить или использовать `beamBroken`
- [ ] **3.2** Добавить программный debounce для кнопок
- [ ] **3.3** Добавить валидацию SSID/password (символы, спецсимволы)
- [ ] **3.4** Вынести pinout в отдельный файл конфигурации платы

---

## История изменений

| Дата | Изменение | Автор |
|---|---|---|
| 20.02.2026 | Создан документ, добавлены все выявленные проблемы | Qwen Code |
| 20.02.2026 | Исправлено **0.1**: Добавлены функции безопасного доступа `getCurrentValueSafe()`, `getSensorActiveSafe()` | Qwen Code |
| 20.02.2026 | Исправлено **0.3**: `resetMeasurements()` обёрнуто в critical section | Qwen Code |
| 20.02.2026 | Исправлено **0.2**: Рефакторинг `handleSensor()` — добавлен флаг `sensorTriggered`, всё чтение из ISR в critical section | Qwen Code |
| 20.02.2026 | Исправлено **0.4**: Выделение core логики в `src/core/measurement_core.cpp`, side effects в `measurements_side_effects.cpp` | Qwen Code |
| 20.02.2026 | Исправлено **1.2**: mDNS для разрешения IP (`chrono.mg`) | Qwen Code |
| 20.02.2026 | Исправлено **1.5**: `StaticJsonDocument` увеличен до 1200 байт, история ограничена 5 записями | Qwen Code |
| 20.02.2026 | Исправлено **1.6**: `handleCSS/JS` используют `streamFile()`, HTML файлы ограничены ~2KB | Qwen Code |
| 20.02.2026 | **P2.3 Упрощение**: HTML отправляется через `streamFile()` без замен, данные обновляются через WebSocket | Qwen Code |

---

## Приоритеты работы

```
P0 > P1 > P2 > P3
```

**Правило:** Не переходить к следующей категории, пока все проблемы текущей не устранены или не приняты осознанные решения об отложенном исправлении.

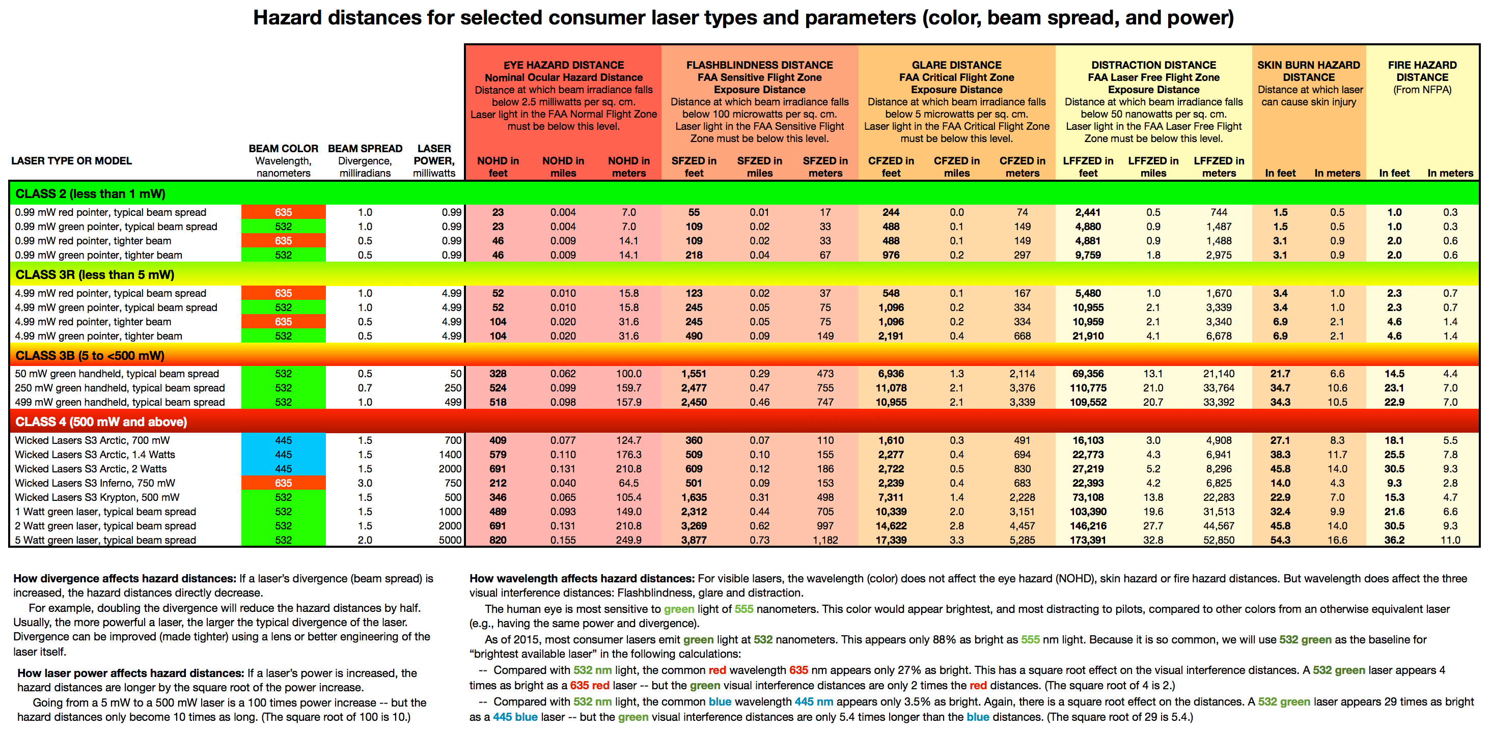
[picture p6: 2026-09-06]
docs/FAA---visible-laser-hazard-calcs-for-LSF-v02.png

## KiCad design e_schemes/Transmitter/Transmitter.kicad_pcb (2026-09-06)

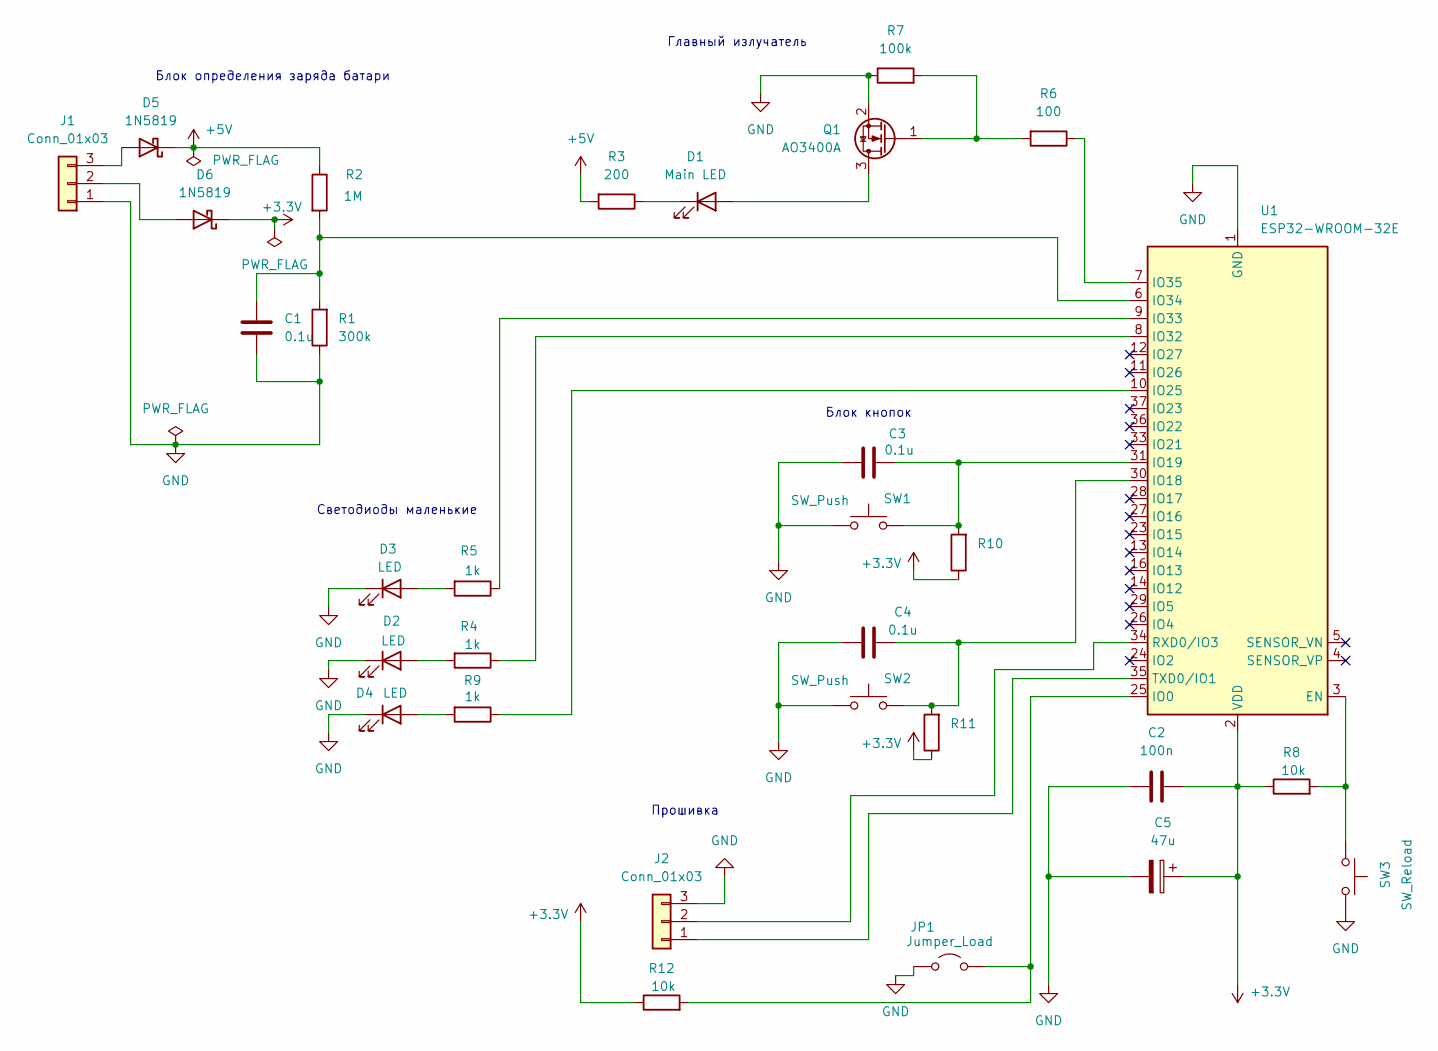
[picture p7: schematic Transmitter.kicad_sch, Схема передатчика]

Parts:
C1, C3, C4: 0.1u; C_Disc_D3.0mm_W1.6mm_P2.50mm
C2: 100n; C_Disc_D3.0mm_W1.6mm_P2.50mm
C5: 47u; C_Disc_D3.0mm_W1.6mm_P2.50mm
D1: Main LED; Osram_BPW82
D2, D3, D4: LED; D_DO-34_SOD68_P2.54mm_Vertical_KathodeUp
D5, D6: 1N5819; D_DO-41_SOD81_P10.16mm_Horizontal
J1: Conn_01x03; Hirose_DF63M-3P-3.96DSA_1x03_P3.96mm_Vertical
J2: Conn_01x03; FanPinHeader_1x03_P2.54mm_Vertical
JP1: Jumper_Load; Jumper_Harwin_S1621_P10.9mm
Q1: AO3400A; SOT-23
R1: 300k; R_Axial_DIN0204_L3.6mm_D1.6mm_P7.62mm_Horizontal
R2: 1M; R_Axial_DIN0204_L3.6mm_D1.6mm_P7.62mm_Horizontal
R3: 200; R_Axial_DIN0204_L3.6mm_D1.6mm_P7.62mm_Horizontal
R4, R5, R9: 1k; R_Axial_DIN0204_L3.6mm_D1.6mm_P7.62mm_Horizontal
R6: 100; R_Axial_DIN0204_L3.6mm_D1.6mm_P7.62mm_Horizontal
R7: 100k; R_Axial_DIN0204_L3.6mm_D1.6mm_P7.62mm_Horizontal
R8, R10, R11, R12: 10k; R_Axial_DIN0204_L3.6mm_D1.6mm_P7.62mm_Horizontal
SW1, SW2: SW_Push; SW_PUSH_1P1T_6x3.5mm_H5.0_APEM_MJTP1250
SW3: SW_Reload; SW_PUSH_1P1T_6x3.5mm_H5.0_APEM_MJTP1250
U1: ESP32-WROOM-32E

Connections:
+3.3V: C2.2, C5.1, D6.1 (K), R8.1, R10.1, R11.1, R12.1, U1.2 (VDD)
+5V: D5.1 (K), R2.1, R3.2
GND: C1.2, C2.1, C3.1, C4.1, C5.2, D2.1 (K), D3.1 (K), D4.1 (K), J1.1, J2.3, JP1.1 (A), Q1.2 (S), R1.1, R7.1, SW1.1, SW2.1, SW3.2, U1.1 (GND), U1.15 (GND), U1.38 (GND), U1.39 (GND); also elsewhere on the board
unnamed: D1.2 (A), Q1.3 (D)
unnamed: D1.1 (K), R3.1
unnamed: D2.2 (A), R4.2
unnamed: D3.2 (A), R5.2
unnamed: D4.2 (A), R9.2
unnamed: D5.2 (A), J1.3
unnamed: D6.2 (A), J1.2
unnamed: J2.1, U1.35 (TXD0/IO1)
unnamed: J2.2, U1.34 (RXD0/IO3)
unnamed: JP1.2 (B), R12.2, U1.25 (IO0)
unnamed: Q1.1 (G), R6.2, R7.2
unnamed 14: R8.2, SW3.1, U1.3 (EN); also elsewhere on the board
unnamed: C4.2, R11.2, SW2.2, U1.30 (IO18)
unnamed: C3.2, R10.2, SW1.2, U1.31 (IO19)
unnamed: R9.1, U1.10 (IO25)
unnamed: R4.1, U1.8 (IO32)
unnamed: R5.1, U1.9 (IO33)
unnamed: C1.1, R1.2, R2.2, U1.6 (IO34)
unnamed: R6.1, U1.7 (IO35)

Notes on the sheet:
Светодиоды маленькие
Прошивка
Блок кнопок
Главный излучатель
Блок определения заряда батари

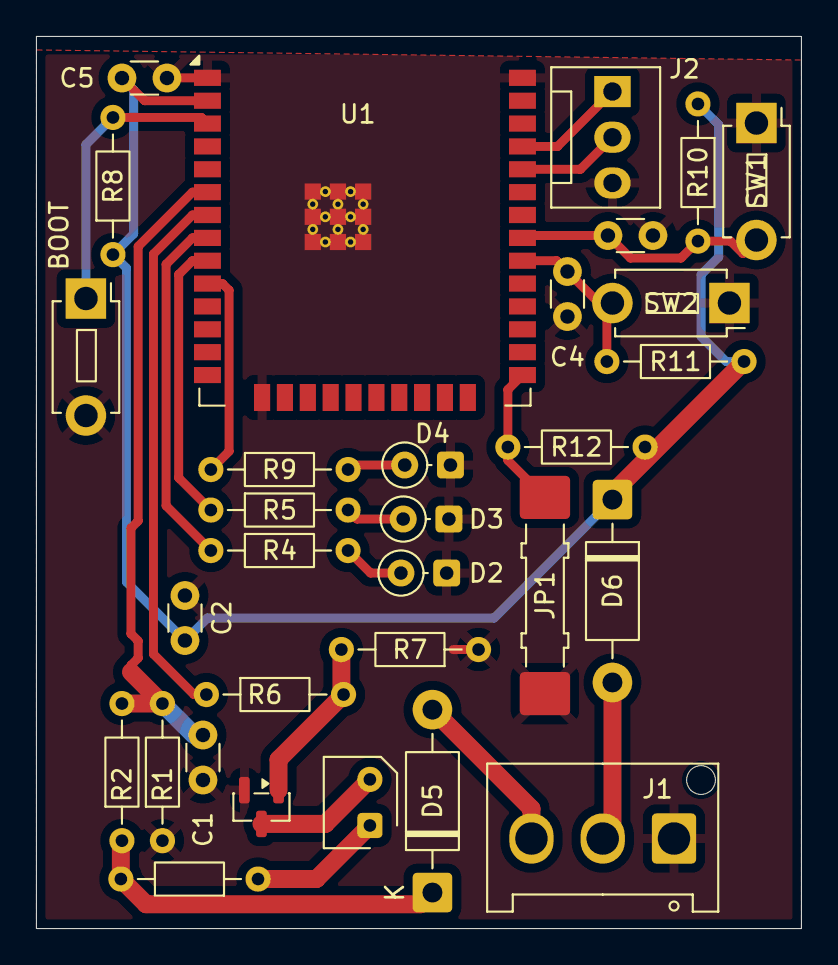
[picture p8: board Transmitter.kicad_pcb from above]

Board: 2 copper layers, 42.5 x 49.6 mm, 31 parts (0 on the bottom side), 22 nets.

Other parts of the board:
BOOT: SW_Reload; SW_PUSH_1P1T_6x3.5mm_H5.0_APEM_MJTP1250

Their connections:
GND: BOOT.2; also elsewhere on the board
unnamed 14: BOOT.1; also elsewhere on the board

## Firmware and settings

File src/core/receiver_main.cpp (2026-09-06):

#include <Arduino.h>
#include <WiFi.h>
#include <WiFiUdp.h>
#include <WebServer.h>
#include <SPIFFS.h>
#include <DNSServer.h>
#include <esp_task_wdt.h>
#include <esp_wifi.h>

#include "utils/receiver_config.h"
#include "modules/web_handlers.h"
#include "modules/websocket_handlers.h"
#include "modules/measurements.h"
#include "drivers/battery/battery.h"
#include "drivers/espnow_receiver.h"
#include "drivers/espnow_broadcast.h"
#include "modules/transmitter_data.h"

// Объявление функций
void updateOperationLed();

// Объявление сервера, определенного в web_handlers.cpp
extern WebServer server;

DNSServer dnsServer;

void onWiFiEvent(WiFiEvent_t event, WiFiEventInfo_t info) {
    // Детектор отключения пользователя, если телефон при отключении
    // высылает пакет об отключении
    if (event == ARDUINO_EVENT_WIFI_AP_STADISCONNECTED) {
        Serial.println("[WiFi] Станция отключилась от AP");
    }
}

void setup() {
  Serial.begin(115200);
  
  // Настройка пинов датчиков как входы для ИК приемников
  
  pinMode(SENSOR_PIN, INPUT);
  
  // Настройка пина светодиода режима работы
  pinMode(OPERATION_MODE_LED_PIN, OUTPUT);
  pinMode(STATUS_IR_LED_PIN, OUTPUT);

  digitalWrite(STATUS_IR_LED_PIN, LOW);
  // При нормальной работе ИК луча на пинах будет LOW (есть сигнал)
  // При пересечении луча на пинах будет HIGH (нет сигнала)
  // Поэтому используем прерывание по RISING (по положительному фронту)
  attachInterrupt(digitalPinToInterrupt(SENSOR_PIN), handleSensor, FALLING);

  if (!SPIFFS.begin(true)) {
    Serial.println("SPIFFS Mount Failed. Formatting...");
  }

    // Загрузка сохраненных настроек wifi
    loadWiFiSettings();
    WiFi.mode(WIFI_AP);        
    WiFi.setSleep(false); 
    
    // Используем сохранённые настройки или константы по умолчанию
    Serial.printf("[WiFi] Создаём AP: SSID=%s, Password=%s\n", ssid, password);
    WiFi.softAP(ssid, password);
  
    Serial.print("Receiver MAC:");
    Serial.println(WiFi.softAPmacAddress());
    
    // Настройка DNS для перенаправления всех запросов
    dnsServer.start(53, "*", WiFi.softAPIP());
    // Установка имени хоста
    WiFi.setHostname("chrono.mg");

    Serial.print("AP IP address: ");
    Serial.println(WiFi.softAPIP());

    // server.on("/api/v1/data", handleData); // Replaced by WebSockets
    server.on("/api/v1/reset", handleReset);
    server.on("/api/v1/mode", HTTP_GET, handleMode);
    
    server.on("/", handleRoot);
    server.on("/wifisettings", handleWiFiSettings);
    server.on("/updatewifi", HTTP_POST, handleUpdateWiFi);
    server.on("/style.css", handleCSS);
    server.on("/script.js", handleJS);
    
    // API для настроек Wi-Fi
    server.on("/api/v1/wifi/settings", HTTP_GET, handleGetWifiSettings);
    server.on("/api/v1/wifi/update", HTTP_POST, handleUpdateWifiPassword);

    server.onNotFound([]() {
        server.send(404, "text/plain", "Not found");
    });
  
    // Инициализация WebSocket
    ws_init();
    ws_start_task();   // вместо server.begin() отдельного вызова ws_loop в основном loop
    server.begin();
    WiFi.onEvent(onWiFiEvent);

    // Инициализация определения заряда батареи
    initReadBattery();
  
    Serial.println("Server is running!");
  
    //инициализция esp-now

    transmitterData_init();  // ← добавить ДО espnow_init()
    espnow_init();

    // инициализация broadcast
    espnow_broadcast_init();
    espnow_broadcast_setInterval(90); // 11 раза в секунду общая рассылка
}

void loop() {
    esp_task_wdt_reset(); 
    
    // ws_loop(); // Обработка WebSocket
    server.handleClient();
    dnsServer.processNextRequest(); // Обработка DNS запросов

    yield();
    // Обработка ESP-NOW пакетов от излучателя
    espnow_loop();

    // Обновление состояния измерений (core + side effects)
    processMeasurementsWithSideEffects();
    
    // Обновление светодиода режима работы
    updateOperationLed();
    handleStatusLED();

    // Определение заряда батареи
    readBattery();
    
    // Запрос статуса заряда у передатчика.
    handleTxReadBattery();

    // Broadcast данных
    espnow_broadcast_loop();

}


void updateOperationLed() {
    static unsigned long lastBlinkTime = 0;
    static bool ledState = false; // false = OFF, true = ON
    static TimerStatus lastStatus = STATUS_READY;

    TimerStatus currentStatus = getTimerStatus();

    // Reset state machine on status change
    if (currentStatus != lastStatus) {
        lastBlinkTime = 0; // Reset blink timer
        ledState = false; // Default to OFF
        digitalWrite(OPERATION_MODE_LED_PIN, LOW);
        lastStatus = currentStatus;
    }

    unsigned long currentTime = millis();

    switch (currentStatus) {
        case STATUS_READY:
            // Normal blink: 0.3s on, 1.7s off
            if (ledState && (currentTime - lastBlinkTime >= LED_BLINK_DURATION)) {
                ledState = false;
                digitalWrite(OPERATION_MODE_LED_PIN, LOW);
                lastBlinkTime = currentTime;
            } else if (!ledState && (currentTime - lastBlinkTime >= (unsigned long)LED_BLINK_INTERVAL - LED_BLINK_DURATION)) {
                ledState = true;
                digitalWrite(OPERATION_MODE_LED_PIN, HIGH);
                lastBlinkTime = currentTime;
            }
            break;

        case STATUS_RUNNING:
            // Fast blink for the first second (MIN_LAP_TIME is in microseconds)
            if (getCurrentRaceTimeSafe() < MIN_LAP_TIME) {
                if (currentTime - lastBlinkTime >= FAST_BLINK_INTERVAL) {
                    ledState = !ledState;
                    digitalWrite(OPERATION_MODE_LED_PIN, ledState ? HIGH : LOW);
                    lastBlinkTime = currentTime;
                }
            } else {
                // After the first second, keep the LED solid ON to indicate the timer is running.
                if (!ledState) {
                    digitalWrite(OPERATION_MODE_LED_PIN, LOW);
                    ledState = true;
                }
            }
            break;

        case STATUS_DISPLAY:
        // Rapid blink for MIN_LAP_TIME duration, then solid ON for the rest of TIMER_COOLDOWN_PERIOD
        if (currentTime - getDisplayStartTimeSafe() < (MIN_LAP_TIME / 1000)) { // MIN_LAP_TIME is in microseconds, convert to milliseconds 
          if (currentTime - lastBlinkTime >= FAST_BLINK_INTERVAL) {
            ledState = !ledState;
            digitalWrite(OPERATION_MODE_LED_PIN, ledState ? HIGH : LOW);
                lastBlinkTime = currentTime;
            }
          } else { 
            // After MIN_LAP_TIME duration, keep the LED solid ON.                                                                                │
            if (!ledState) {
            digitalWrite(OPERATION_MODE_LED_PIN, HIGH);
            ledState = true;
          }
        }
        break;
    }

}

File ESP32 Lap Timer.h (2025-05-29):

#include <WiFi.h>
#include <WebServer.h>
#include <SPIFFS.h>

// Конфигурация
#define SENSOR1_PIN 13
#define SENSOR2_PIN 12
#define DEBOUNCE_TIME 50
#define MIN_LAP_TIME 3000000
#define HISTORY_SIZE 5

WebServer server(80);

enum Mode { SPEEDOMETER, LAP_TIMER, RACE_TIMER };
Mode currentMode = SPEEDOMETER;
float distance = 10.0;

struct Measurement {
  float value;
  unsigned long timestamp;
};

Measurement speedHistory[HISTORY_SIZE];
Measurement lapHistory[HISTORY_SIZE];
int historyIndex = 0;
volatile unsigned long startTime = 0;
volatile unsigned long endTime = 0;
volatile bool sensor1Triggered = false;
volatile bool sensor2Triggered = false;
volatile bool measurementReady = false;
volatile float currentValue = 0.0;

const char* htmlPage = R"rawliteral(
<!DOCTYPE html>
<html>
<head>
  <meta charset="UTF-8">
  <meta name="viewport" content="width=device-width, initial-scale=1.0">
  <title>Motogymkhana Tool Kit (Speedometer, Lap/Race Timer)</title>
  <style>
    body {
      font-family: Arial, sans-serif;
      margin: 0;
      padding: 20px;
      background-color: #f5f5f5;
    }
    .container {
      max-width: 600px;
      margin: 0 auto;
      background: white;
      padding: 20px;
      border-radius: 10px;
      box-shadow: 0 0 10px rgba(0,0,0,0.1);
    }
    .controls {
      margin: 20px 0;
      display: flex;
      flex-wrap: wrap;
      gap: 10px;
      align-items: center;
    }
    .display {
      text-align: center;
      margin: 30px 0;
    }
    .main-value {
      font-size: 4rem;
      font-weight: bold;
      color: #2c3e50;
    }
    .unit {
      font-size: 1.5rem;
      color: #7f8c8d;
    }
    .timer-status {
      font-size: 1.2em;
      color: #e74c3c;
      margin: 10px 0;
      height: 1.5em;
    }
    @keyframes pulse {
      0% { opacity: 1; }
      50% { opacity: 0.5; }
      100% { opacity: 1; }
    }
    .timer-status.running {
      animation: pulse 1.5s infinite;
      color: #e74c3c;
      font-weight: bold;
    }
    .history {
      margin-top: 30px;
    }
    table {
      width: 100%;
      border-collapse: collapse;
    }
    th, td {
      padding: 10px;
      text-align: left;
      border-bottom: 1px solid #ddd;
    }
    th {
      background-color: #f2f2f2;
    }
    button, select, input {
      padding: 8px 12px;
      border-radius: 4px;
      border: 1px solid #ddd;
    }
    button {
      background-color: #3498db;
      color: white;
      border: none;
      cursor: pointer;
    }
    button:hover {
      background-color: #2980b9;
    }
    .distance-control {
      display: flex;
      align-items: center;
      gap: 5px;
    }
    #distanceInput {
      width: 60px;
    }
    @media (max-width: 480px) {
      .main-value {
        font-size: 3rem;
      }
      .controls {
        flex-direction: column;
        align-items: stretch;
      }
    }
  </style>
</head>
<body>
  <div class="container">
    <h1>Motogymkhana Tool Kit (Speedometer, Lap/Race Timer)</h1>
    
    <div class="controls">
      <select id="modeSelect" onchange="changeMode()">
        <option value="0">Speedometer</option>
        <option value="1">Lap Timer</option>
        <option value="2">Race Timer</option>
      </select>
      
      <div id="distanceControl" class="distance-control">
        <label>Distance (m):</label>
        <input type="number" id="distanceInput" step="0.1" min="0.1" value="10.0">
        <button onclick="updateDistance()">Update</button>
      </div>
      
      <button onclick="reset()">Reset</button>
    </div>
    
    <div class="display">
      <div id="valueDisplay" class="main-value">0.00</div>
      <div id="unitDisplay" class="unit">km/h</div>
      <div class="timer-status" id="timerStatus"></div>
    </div>
    
    <div class="history">
      <h2>History</h2>
      <table id="historyTable">
        <thead>
          <tr>
            <th>#</th>
            <th>Value</th>
            <th>Time</th>
          </tr>
        </thead>
        <tbody id="historyBody"></tbody>
      </table>
    </div>
  </div>
  
  <script>
    let currentMode = 0;
    let historyData = [];
    let timerStatus = document.getElementById('timerStatus');

      function formatTime(seconds) {
        if(isNaN(seconds)) return "00:00.000";
        const mins = Math.floor(seconds / 60);
        const secs = (seconds % 60).toFixed(3);
        return `${mins.toString().padStart(2, '0')}:${secs.padStart(6, '0')}`;
      }


    function updateDisplay() {
      fetch('/data')
        .then(response => response.json())
        .then(data => {
          currentMode = data.mode;
          document.getElementById('modeSelect').value = currentMode;
          document.getElementById('distanceInput').value = data.distance;
          
          // Update main display
          const valueDisplay = document.getElementById('valueDisplay');
          const unitDisplay = document.getElementById('unitDisplay');
          
          if (currentMode == 0) {
            valueDisplay.textContent = data.currentValue.toFixed(2);
            unitDisplay.textContent = 'km/h';
            historyData = data.speedHistory;
            timerStatus.textContent = "";
            timerStatus.className = "timer-status";
          } else {
            valueDisplay.textContent = formatTime(data.currentValue);
            unitDisplay.textContent = '';
            historyData = data.lapHistory;
            
            if (data.sensor1Triggered && !data.sensor2Triggered) {
              timerStatus.textContent = "⏱ Timer running...";
              timerStatus.className = "timer-status running";
            } else {
              timerStatus.textContent = data.currentValue > 0 ? "✔ Ready" : "Waiting...";
              timerStatus.className = "timer-status";
            }
          }
          
          // Update history table
          const tableBody = document.getElementById('historyBody');
          tableBody.innerHTML = '';
          
          for (let i = 0; i < historyData.length; i++) {
            if (historyData[i].value > 0) {
              const row = document.createElement('tr');
              
              const indexCell = document.createElement('td');
              indexCell.textContent = i + 1;
              row.appendChild(indexCell);
              
              const valueCell = document.createElement('td');
              valueCell.textContent = currentMode == 0 ? 
                historyData[i].value.toFixed(2) + ' km/h' : 
                formatTime(historyData[i].value);
              row.appendChild(valueCell);
              
              const timeCell = document.createElement('td');
              const date = new Date(historyData[i].time);
              timeCell.textContent = date.toLocaleTimeString();
              row.appendChild(timeCell);
              
              tableBody.appendChild(row);
            }
          }
        })
        .catch(error => console.error('Error:', error));
    }
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

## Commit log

2025-05-29 Create ESP32 Lap Timer
    init
2025-05-29 Rename ESP32 Lap Timer to ESP32 Lap Timer.h
2025-05-29 Налаженно расположение файлов, чтобы Arduino IDE не ругалось
2025-06-10 Переделано все на VSCode и Platformio
2025-06-10 ADD: последовательный вывод истории изменений
2025-06-11 ADD: Отображение времени в формате mm:ss.ms Анимация отображения замеров вывод последовательно истории замеров
2025-07-03 ADD: Добавлено отображение сработки датчиков пересечения луча
2025-07-22 ADD: Добавлена DNS запись
2025-07-25 ADD: Добавлена возможность смены SSID, pass для wi-fi
2025-07-25 REF: вебконтент настройки wifi в отдельный файл
2025-07-28 ADD: Добавлено отображение данных таймера в ральном времени. Добавлена задержка между измерениями 5секунд
2025-07-28 ADD: Подсветка сработавших датчиков 3сек
2025-07-28 REF: ручки переписаны на api пути.
2025-07-29 ADD: Добавлено отображение заряда батареи
2025-07-30 ADD: Коммутация датчиков через +3.3 В( NPN NO)
2025-08-28 ADD: Рекомендация по используемым пинам подключения датчиков.
2025-08-29 Использованы D14 D27 для получаения данных датчика
2025-08-31 REF: Изменено время задержки срабатывания датчиков пересечения и минимальное время круга до 1 сек
2026-01-15 FIX: Использование атомарных операций для доступа к общим переменным для исключения "гонки даных" при одновременном доступе из прерываний и основного цикла.
    [web_handlers.cpp]
2026-01-15 FIX: Проблемы с утечкой памяти. использование статичное выделение памяти вместо динамического (strdup())
2026-01-15 FIX: решение проблемы потенциального переполнения при работе с микросекунлдами - добавлены механизмы синхронизации для безопасного доступа к переменным из разных частей программы.
    [web_handlers.cpp]
2026-01-15 FIX: отображения времения в веб интерфейсе
    [web_handlers.cpp]
2026-01-15 FIX: переменные исправлены на long long для исключения возможности переполнения.
2026-01-16 BUG FIX: исправление ошибки std::atomic
    [web_handlers.cpp]
2026-01-16 FEAT: Пределан принцип работы на работу с IR светодиодами TSOP 38khz.
2026-01-16 ADD: Разделение на 2 датчика Излучатель / приемник
2026-01-18 FEAT: Переработан дизайн на работу кругового таймера, обновлен дизайн страницы
2026-01-18 ADD: Добавлен селектор выбора режима работы
2026-01-18 BUGFIX: оптимизация памяти вызывающая зависание процессора
    [web_handlers.cpp]
2026-01-19 dev: В консоль выводится правильные значения таймера, но в UI поломался "Живой таймер".
2026-01-19 FIX: проблемы живого таймера
    [web_handlers.cpp]
2026-01-19 FIX: 1) Устранена фрагментация памяти веб страницы перенесены в FS отдел памяти и не генерируется процесосром 2) TX в случае невозхможности подключения трансмиттер просто продолжает работать как пере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
    [web_handlers.cpp]
2026-01-19 REF: Удаление неиспользуеммых переменных, в данный момент работает режи LapTimer Only.
2026-01-26 FIX: После остановки таймера - режим остывания 5 секунд, показания не принимаются, так же добавлен индикатор
    [receiver_config.h, web_handlers.cpp]
2026-01-26 ADD: Переписан код на использование вебсокетов для отображения таймера реал-тайм
2026-01-27 REF: Переделана формула расчета заряда батареи,используются менее энергозатратные резисторы с возможностью изменения сопротивления
2026-01-27 ADD: Добавлен светодиод с отображением работы хрономентрии на ГПИО 34
2026-01-28 ADD: Добавлено моргание светодиода при финише.
2026-01-28 refactoring: проблема с общим доступом к данным при добавлении в историю заездов
2026-01-28 feat: рассчет заряда аккумулятора через коэфф (начальная калибровка)
2026-01-29 калибровка батареи
2026-01-30 REF: Вынос рассчета аккумулятора в отдельныее файлы. геттеры для получения данных о заряде аккумулятора и напряжении
2026-02-01 REF: использования функции батарии для передатчика + рефакторинг
2026-02-01 ADD: Скрипт который не дает погаснуть экрану(not work)
2026-02-06 ADD: Спектограмма лазера
2026-02-08 ADD: Test нахождения длительности пачки до того как TSOP
2026-02-08 ADD: Описание websocket связи
2026-02-10 FEAT: переход на режим постоянного свечения, т.к. меняется концепция(не модуляция сигнала а постоянное его присутствие)
2026-02-10 Оладка режима получения с батарейки
2026-02-10 UPDATE: Обновлена информация по передатчику.
2026-02-12 DEL: Удалена модуляция с TSOP
2026-02-12 Refactoring: Удаление лишних файлов т..к архитектурное решение через TSOP зашло в тупик
2026-02-13 Черновик
2026-02-13 ADD: заготовка схемы для трассировки
    [Transmitter.kicad_pcb, Transmitter.kicad_sch]
2026-02-14 ADD: добавлена распиновка
2026-02-15 ADD: Добавлены электросхемы
    [Reciever.kicad_pcb, Reciever.kicad_sch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]
2026-02-16 ADD: Схема приемника
    [Reciever.kicad_sch]
2026-02-16 ADD: (processed) Добавление светодиода состояния\
2026-02-18 Feat: добавлен светодиод состояния луча + рефакторинг(убрана функция спидометра)
2026-02-18 UPDATE: схема RX
    [Reciever.kicad_pcb, Reciever.kicad_sch]
2026-02-19 FIX: Чистка кода
2026-02-19 Bugfix: фикс двойного чтения статуса
    [websocket_handlers.cpp]
2026-02-19 FIX: отображение статуса при конце круга.
2026-02-20 Отрисовка схемы
    [Reciever.kicad_pcb, Reciever.kicad_sch]
2026-02-20 FIX: получение текущего значения времени и статуса сенсора через безопасную функцию.
    [web_handlers.cpp, websocket_handlers.cpp]
2026-02-24 ref: удаление serial значений при получении данных батареи
2026-02-24 REF: Раделение логики UI и core, side_effects вынесены в отдельные функции.
2026-02-24 ADD: размер пакета ws
2026-02-24 rx scheme1
    [Reciever.kicad_pcb, Reciever.kicad_sch]
2026-02-25 REF: цпрощение отправки html страницы, и обновление динамических данных через JS + ws
2026-02-25 ADD: Установка пароля точки доступа через страницу настроек. Добавление UTF-8. Сохранение пароля в eeprom
2026-02-26 Получение значений аккумулятора через ESP-NOW между двумя esp32
2026-02-26 FEAT: Переделана формула расчета заряда батареи average -> EMA.
2026-02-26 REF: удаление дублирующего кода, UDP устаревшего
2026-02-27 ADD: добавление broadcast рассылки данных
2026-08-20 REF: Разбитие кода по модулям
2026-08-20 ADD: Добавление тестов
2026-08-26 REF: Изменил пины LED
2026-08-26 FIX: ОТключено постоянное горение при измерении
    [receiver_main.cpp]
2026-08-26 FIX: Фикс бага с отображением времени, когда гонка остановлена
2026-08-31 FIX[TX]: Отобржание данных в сериал принт полученных по esp-now
    [espnow_transmitter.cpp]
2026-08-31 REF TX: отображние в сериал принт информации о передаче данных в esp-now
2026-08-31 FIX: Установка жестко канала трансляции вифи, для лучшей стабильности esp-now(при переключении канала может вызывать конфликт)
    [receiver_main.cpp]
2026-08-31 BUGFIX [RX]: Фикс бага при разрыве wifi соединения. При отсутствии ack ответа получаем переполнения буфера
    [websocket_handlers.cpp]
2026-09-01 BUGFIX[Rx]: при отключении пользователя от wifi , ws вызывает зависание контроллера, добавлено
    [espnow_receiver.cpp, ir_transmitter.cpp, receiver_main.cpp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]
2026-09-02 FEAT: Добавление LED для отображения состояние заряда аккумулятора
2026-09-02 FEAT: Добавлен HEARTBEAT для отображения работы
2026-09-04 add 3d model
    [ESP32 Case- Батарейка.stl, ESP32 Case-ESP32 Case.stl, ESP32 Case-Крышка.stl]
2026-09-05 Схемы добвлены
2026-09-05 ADD: 3d model freecad
    [ESP32 Case.FCStd]
